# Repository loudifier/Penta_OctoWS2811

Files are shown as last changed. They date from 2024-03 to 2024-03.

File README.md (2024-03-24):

# Penta_OctoWS2811
Adapter board for driving 40 channels of WS2811-style addressable LED strips with a Teensy 4.1 microcontroller

This is a work in progress. A prototype board has been assembled, but I am waiting on parts to test Ethernet, and I am working on a sketch for testing that works better than the teensyduino examples for thousands of LEDs. Committing what I have so far.

[photo of board and LEDs]

The **Penta**_OctoWS2811 is effectively five of the [PJRC OctoWS2811 adapter](https://www.pjrc.com/store/octo28_adaptor.html) squished into a single board for an easy way to take full advantage of the Teensy 4.1's ability to use any set of GPIO pins with the OctoWS2811 library. Penta_OctoWS2811 also adds an Ethernet connector for use with ArtNet or other networked light controller, and a voltage regulator so the board and Teensy can be powered from the LED power supply without USB.

[image of schematic]

## Features

The Penta_OctoWS2811 board has 10 RJ45 ports, for a total of 40 output channels driven from 5V buffers through 100Ω termination resistors. Teensy 4.0 can also be used with this board, supporting up to 24 output channels.

## Usage

The instructions and guidelines on the PJRC website and Teensyduino example scketches for using a Teensy and OctoWS2811 to drive addressible LED strips over CAT6 wires apply equally to the PJRC OctoWS2811 adapter and the Penta_OctoWS2811 board, except for a few key features noted below.

### Output Pins

Teensy 4.1 digital output pins are connected to the following RJ45 ports:  
 Port - GPIO pins  
  J2 - 1, 2, 3, 4  
  J3 - 5, 6, 7, 8  
  J4 - 25, 26, 27, 28  
  J5 - 29, 30, 31, 32  
  J6 - 23, 22, 21, 20  
  J7 - 17, 16, 15, 14  
  J8 - 40, 39, 38, 37  
  J9 - 36, 35, 34, 33  
  J10 - 13, 18, 19, 9  
  J11 - 11, 12, 41, 24

Teensy 4.0 is compatible with the board, and will be connected to J2, J3, J6, J7, J10, and J11. In order to get a full 24 channels of output with Teensy 4.0, GPIO 0 can be used instead of GPIO 41 and GPIO 12 can be used instead of GPIO 24 by shorting jumper pads on the bottom of the board.

A frame sync output is provided, if you somehow need even more output channels and need to maintain accurate timing between multiple boards. The connector can also be useful for connecting to a single 3.3V-compatible LED strip. If you need to use GPIO 12 for SPI communication, you can cut and jump the appropriate pads on the bottom of the board to use GPIO 0 instead.

### Power

Just like the PJRC OctoWS2811 adapter, the Penta_OctoWS2811 board can be powered from your LED power supply. The Penta_OctoWS2811 board adds a voltage regulator for compatibility with newer 12V LED strips. If you are using 5V LEDs, the voltage regulator should be bypassed using the jumper pads on top of the board.

**The Teensy VUSB jumper must be cut if you plan to power the board from the LED power supply.** If you cut the VUSB jumper you can add a single header pin connection fom the Teensy VUSB pad to a corresponding pad on the board, which will allow the Teensy and board to be powered from the LED power supply or USB via a diode.

### Ethernet

## Board Design, Pre-assembled Boards

## Testing

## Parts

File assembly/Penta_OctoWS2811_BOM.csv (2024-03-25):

Designator | Qty | Description | Manufacturer Part Number | Manufacturer | Supplier | DNP
C1,C2,C5,C6,C7,C9 | 6 | CAP 0.1uF 0603 50V X7R 10% | CC0603KRX7R9BB104 | Yageo | LCSC
C3,C4,C8 | 3 | CAP 10uF 0603 25V X5R 20% | CL10A106MA8NRNC | Samsung | LCSC
D1 | 1 | BAT54C dual Schottky barrier diode, common cathode | BAT54C,215 | Nexperia | LCSC
J1 | 1 | 3 pin screw terminal block, 5.08mm pitch | DB127V-5.08-3P-GN-S | Dorabo | LCSC
J2,J3,J4,J5,J6,J7,J8,J9,J10,J11 | 10 | RJ45 jack, 8P8C, unshielded | HC-RJ45-5622-1-6 | HCTL | LCSC
J12 | 1 | RJ45 magjack | J1B1211CCD | WIZnet | LCSC
J13 | 1 | 2x3 2mm header receptacle | ZX-PM2.0-2-3PY | Megastar | LCSC
J14,J15 | 2 | 1x24 2.54mm header receptacle | X6511FV-24-C85D32 | Megastar
J16 | 1 | Single pin 2.54mm header receptacle (use single segment from breakaway strip)
R1,R2,R3,R4,R5,R6,R7,R8,R9,R10,R11,R12,R13,R14,R15,R16,R17,R18,R19,R20,R21,R22,R23,R24,R25,R26,R27,R28,R29,R30,R31,R32,R33,R34,R35,R36,R37,R38,R39,R40,R41 | 41 | RES 100R 0603 1/16W 1% | 0603WAF1000T5E | Uniroyal | LCSC
U1,U2,U5,U6,U7 | 5 | 74HCT245 Octal BUS Transceiver, 3-State outputs, TTL input | 74HCT245D,653 | Nexperia | LCSC
U3 | 1 | NCP1117 1A Low drop-out regulator, Fixed 5.0V, SOT-223 | NCP1117LPST50T3G | onsemi | LCSC

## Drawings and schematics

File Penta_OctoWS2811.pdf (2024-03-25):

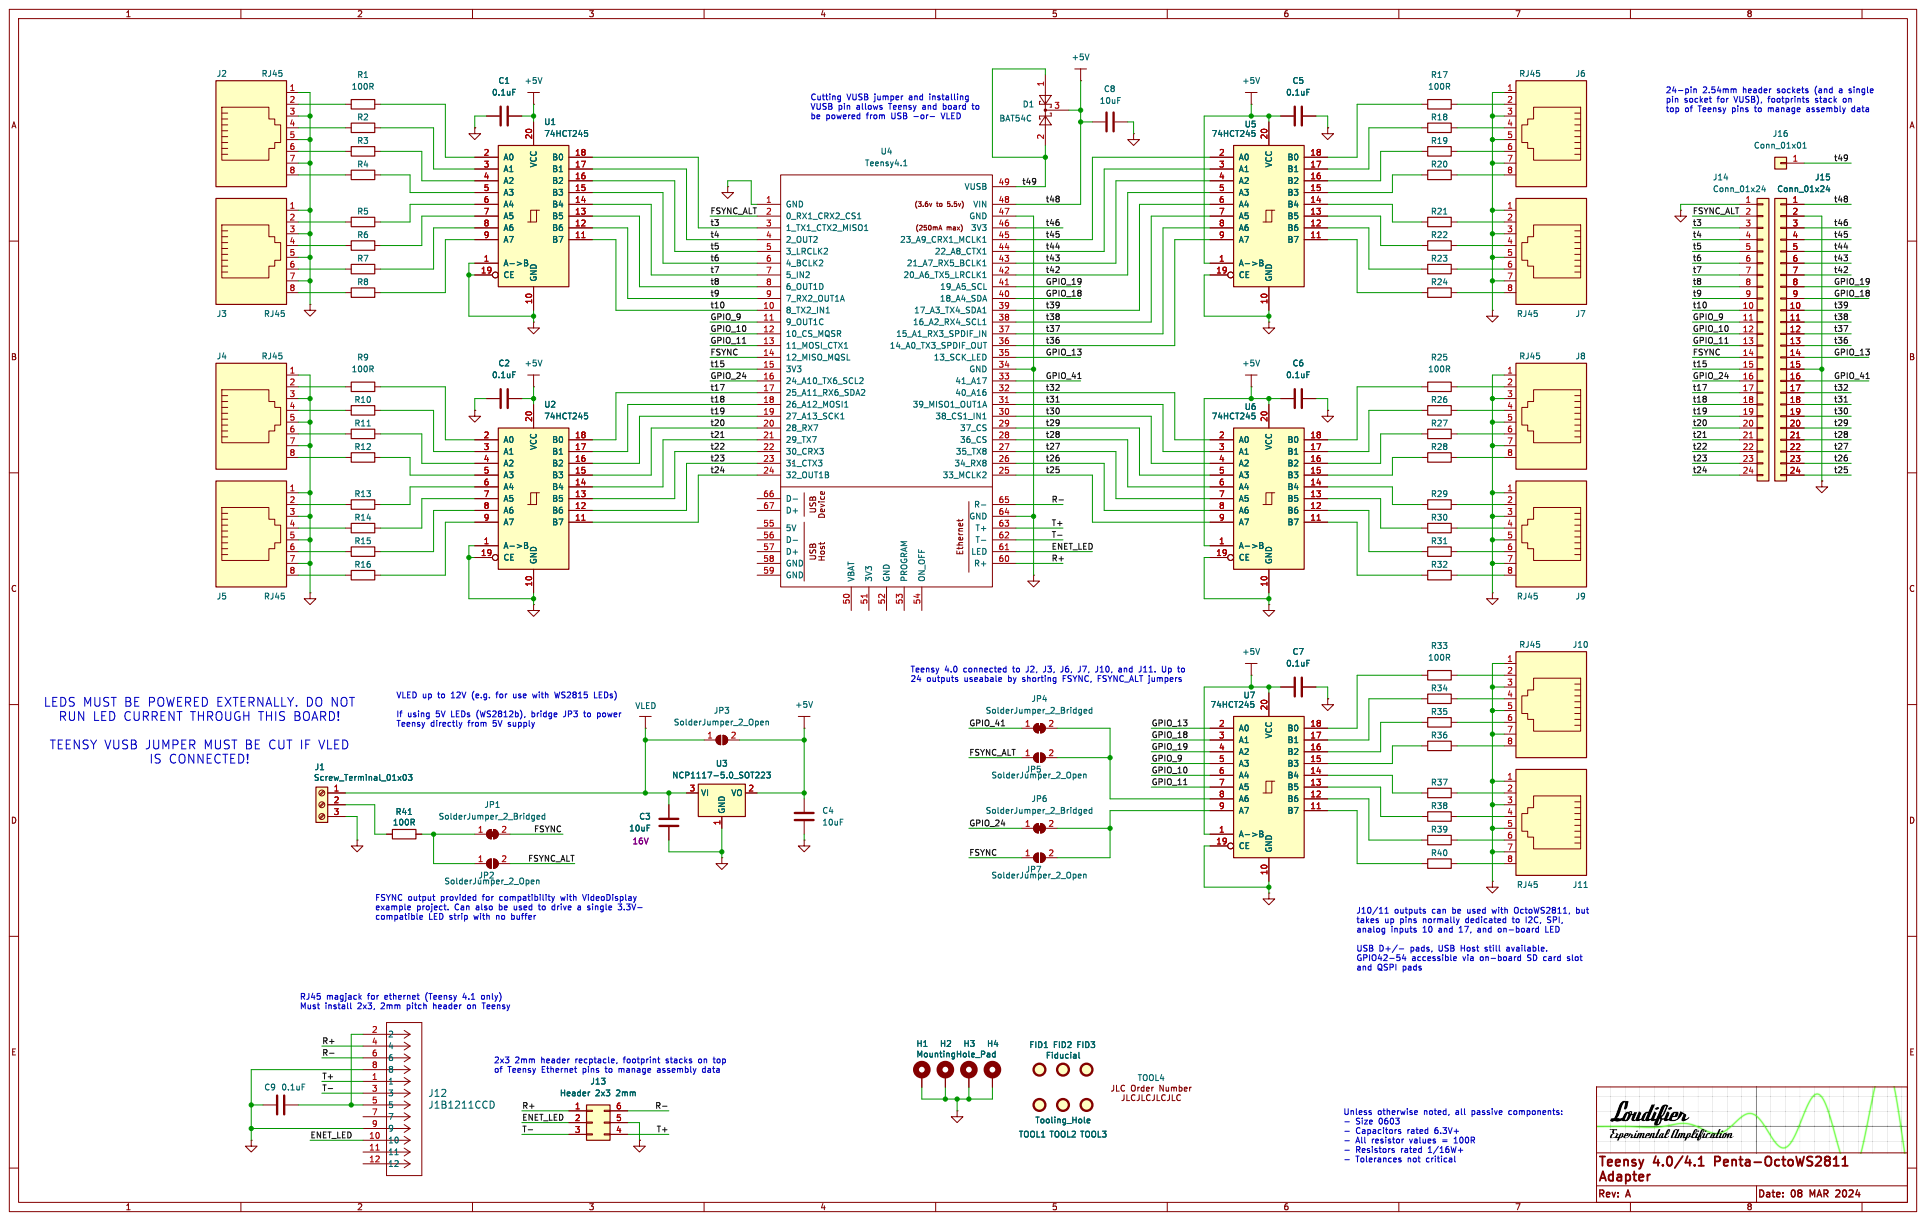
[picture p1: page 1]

top of Teensy pins to manage assembly data

Cutting VUSB jumper and installing VUSB pin allows Teensy and board to

RUN LED CURRENT THROUGH THIS BOARD!

VLED up to 12V (e.g. for use with WS2815 LEDs)

TEENSY VUSB JUMPER MUST BE CUT IF VLED

of Teensy Ethernet pins to manage assembly data

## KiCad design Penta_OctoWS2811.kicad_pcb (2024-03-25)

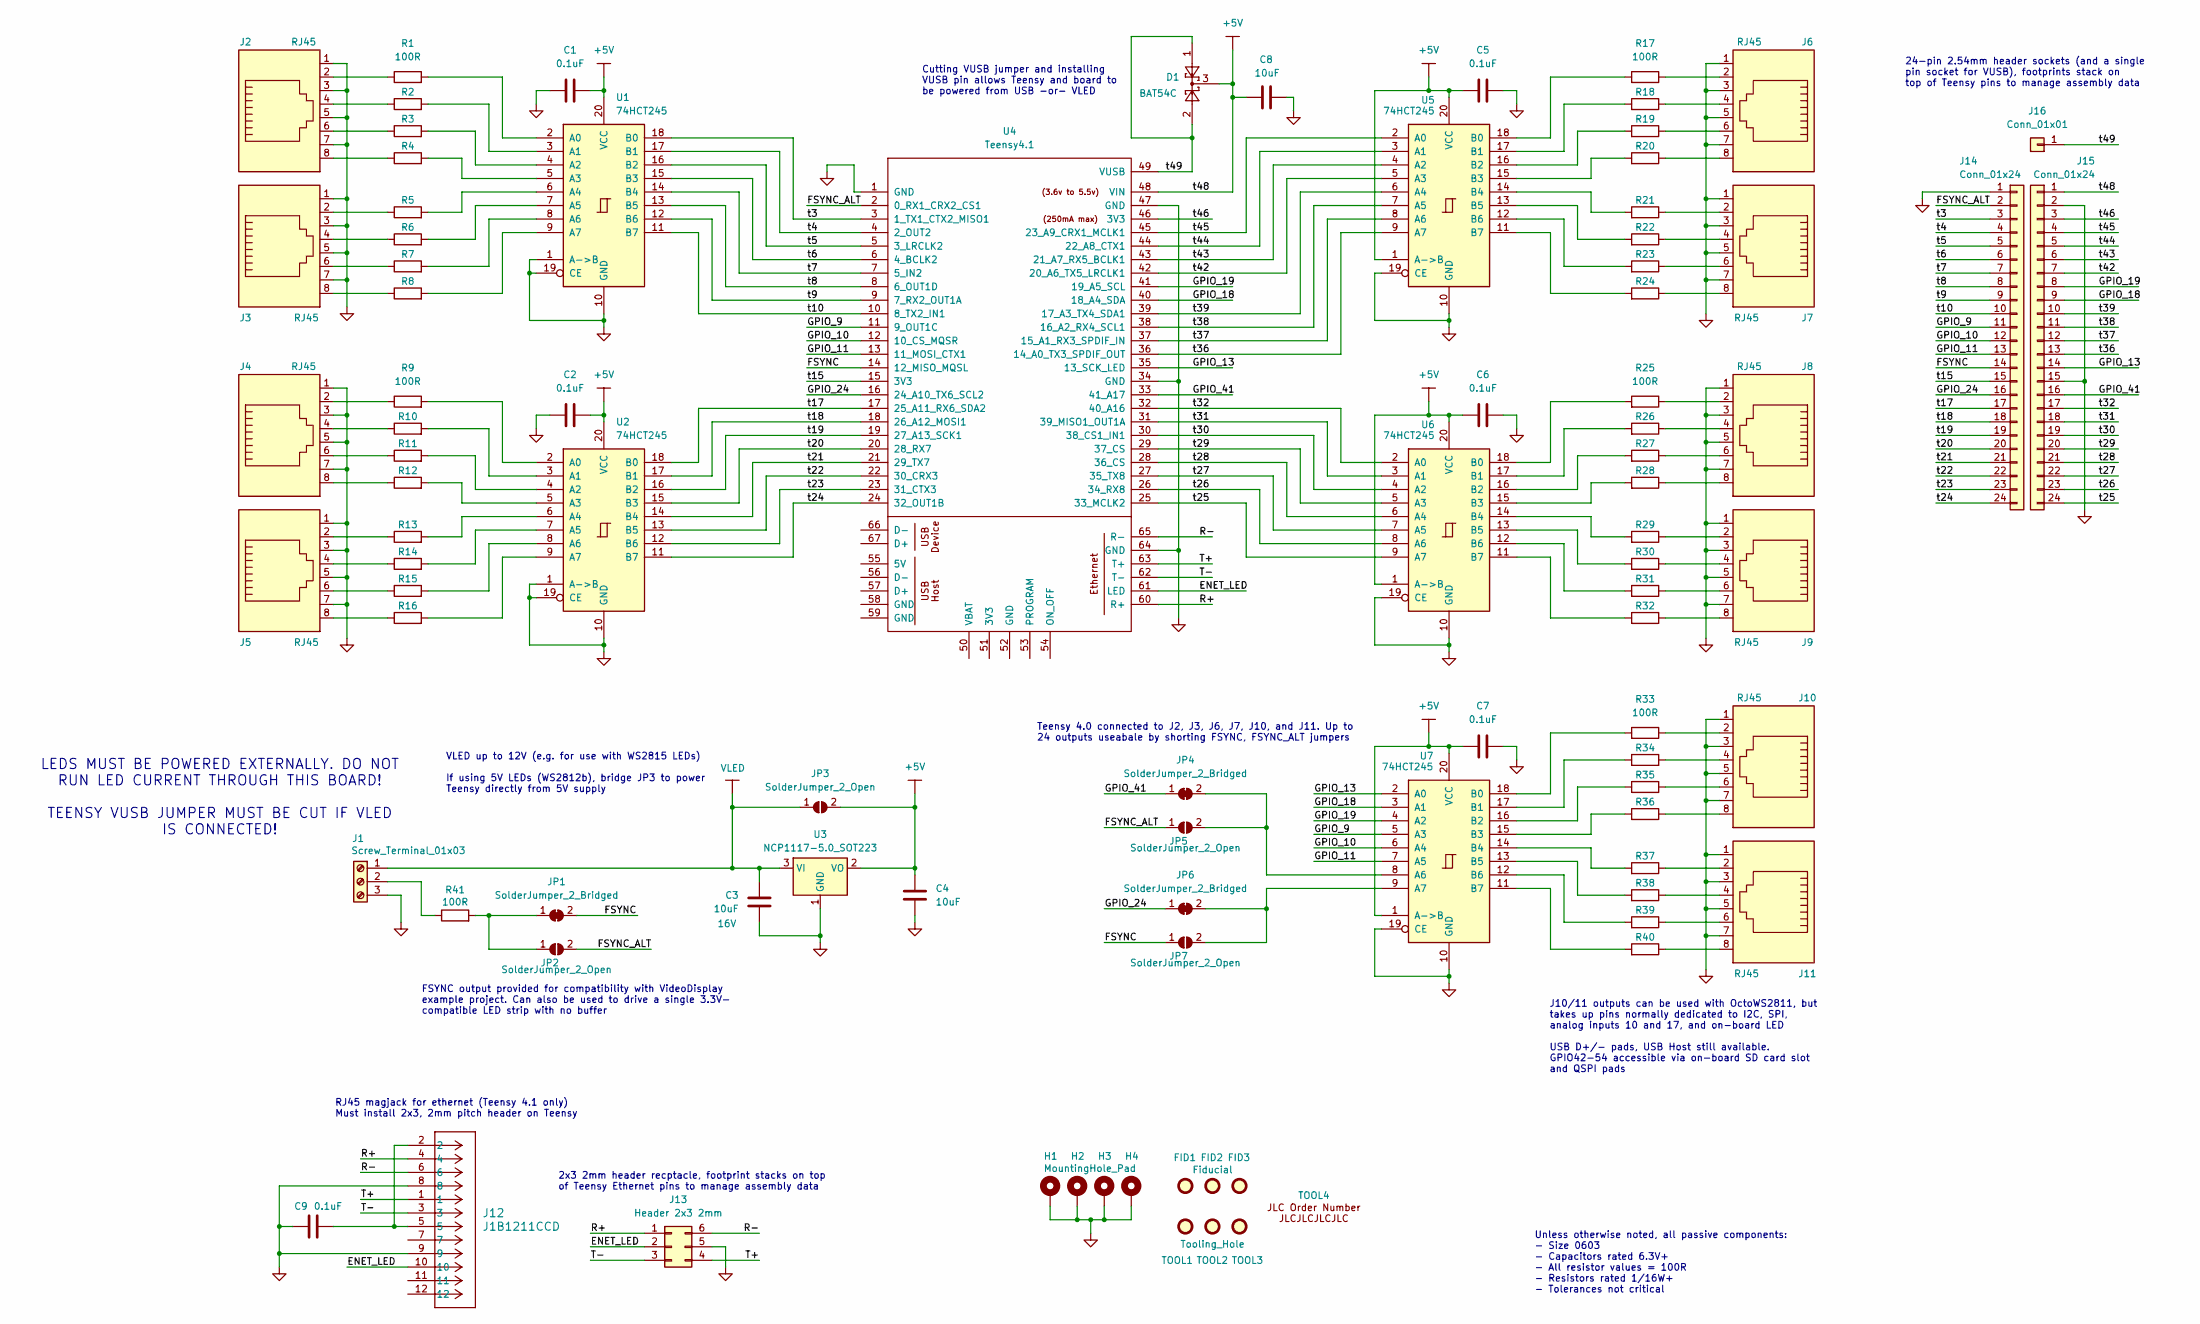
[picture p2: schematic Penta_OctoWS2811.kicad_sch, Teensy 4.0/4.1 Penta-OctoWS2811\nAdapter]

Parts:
C1, C2, C5, C6, C7, C9: 0.1uF; C_0603_1608Metric_Pad1.08x0.95mm_HandSolder; Manufacturer Part Number CC0603KRX7R9BB104
C3: 10uF; C_0603_1608Metric_Pad1.08x0.95mm_HandSolder; Voltage 16V; Manufacturer Part Number CL10A106MA8NRNC
C4, C8: 10uF; C_0603_1608Metric_Pad1.08x0.95mm_HandSolder; Manufacturer Part Number CL10A106MA8NRNC
D1: BAT54C; SOT-23; Manufacturer Part Number BAT54C,215
FID1, FID2, FID3: Fiducial; Fiducial_0.5mm_Mask1mm
H1, H2, H3, H4: MountingHole_Pad; MountingHole_5.3mm_M5_Pad
J1: Screw_Terminal_01x03; TerminalBlock_bornier-3_P5.08mm; Manufacturer Part Number DB127V-5.08-3P-GN-S
J2, J3, J4, J5, J6, J7, J8, J9, J10, J11: RJ45; HCTL HC-RJ45-5622-1-6; Manufacturer Part Number HC-RJ45-5622-1-6
J12: J1B1211CCD; CONN12_J1B1211CCD_WIZ; Manufacturer Part Number J1B1211CCD
J13: Header 2x3 2mm; PinSocket_2x03_P2.00mm_Vertical; Manufacturer Part Number ZX-PM2.0-2-3PY
J14, J15: Conn_01x24; PinSocket_1x24_P2.54mm_Vertical; Manufacturer Part Number X6511FV-24-C85D32
J16: Conn_01x01; PinSocket_1x01_P2.54mm_Vertical
JP1, JP4, JP6: SolderJumper_2_Bridged; SolderJumper-2_P1.3mm_Bridged_RoundedPad1.0x1.5mm
JP2, JP3, JP5, JP7: SolderJumper_2_Open; SolderJumper-2_P1.3mm_Open_RoundedPad1.0x1.5mm
R1, R2, R3, R4, R5, R6, R7, R8, R9, R10, R11, R12, R13, R14, R15, R16, R17, R18, R19, R20, R21, R22, R23, R24, R25, R26, R27, R28, R29, R30, R31, R32, R33, R34, R35, R36, R37, R38, R39, R40, R41: 100R; R_0603_1608Metric_Pad0.98x0.95mm_HandSolder; Manufacturer Part Number 0603WAF1000T5E
TOOL1, TOOL2, TOOL3: Tooling_Hole; Tooling Hole
TOOL4: Order Number
U1, U2, U5, U6, U7: 74HCT245; SOIC-20W_7.5x12.8mm_P1.27mm; Manufacturer Part Number 74HCT245D,653
U3: NCP1117-5.0_SOT223; SOT-223-3_TabPin2; Manufacturer Part Number NCP1117LPST50T3G
U4: Teensy4.1; Teensy41

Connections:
+5V: C1.2, C2.2, C4.2, C5.2, C6.2, C7.2, C8.2, D1.3, J15.1, JP3.2 (B), U1.20 (VCC), U2.20 (VCC), U3.2 (VO), U4.48 (VIN), U5.1 (A->B), U5.20 (VCC), U6.1 (A->B), U6.20 (VCC), U7.1 (A->B), U7.20 (VCC)
/ENET_LED: J12.10, J13.2, U4.61 (LED)
/FSYNC: J14.14, JP1.2 (B), JP7.1 (A), U4.14 (12_MISO_MQSL)
/FSYNC_ALT: J14.2, JP2.2 (B), JP5.1 (A), U4.2 (0_RX1_CRX2_CS1)
/GPIO_9: J14.11, U4.11 (9_OUT1C), U7.5 (A3)
/GPIO_10: J14.12, U4.12 (10_CS_MQSR), U7.6 (A4)
/GPIO_11: J14.13, U4.13 (11_MOSI_CTX1), U7.7 (A5)
/GPIO_13: J15.14, U4.35 (13_SCK_LED), U7.2 (A0)
/GPIO_18: J15.9, U4.40 (18_A4_SDA), U7.3 (A1)
/GPIO_19: J15.8, U4.41 (19_A5_SCL), U7.4 (A2)
/GPIO_24: J14.16, JP6.1 (A), U4.16 (24_A10_TX6_SCL2)
/GPIO_41: J15.16, JP4.1 (A), U4.33 (41_A17)
/R+: J12.4, J13.1, U4.60 (R+)
/R-: J12.6, J13.6, U4.65 (R-)
/T+: J12.1, J13.4, U4.63 (T+)
/T-: J12.3, J13.3, U4.62 (T-)
/t3: J14.3, U1.18 (B0), U4.3 (1_TX1_CTX2_MISO1)
/t4: J14.4, U1.17 (B1), U4.4 (2_OUT2)
/t5: J14.5, U1.16 (B2), U4.5 (3_LRCLK2)
/t6: J14.6, U1.15 (B3), U4.6 (4_BCLK2)
/t7: J14.7, U1.14 (B4), U4.7 (5_IN2)
/t8: J14.8, U1.13 (B5), U4.8 (6_OUT1D)
/t9: J14.9, U1.12 (B6), U4.9 (7_RX2_OUT1A)
/t10: J14.10, U1.11 (B7), U4.10 (8_TX2_IN1)
/t15: J14.15, U4.15 (3V3)
/t17: J14.17, U2.18 (B0), U4.17 (25_A11_RX6_SDA2)
/t18: J14.18, U2.17 (B1), U4.18 (26_A12_MOSI1)
/t19: J14.19, U2.16 (B2), U4.19 (27_A13_SCK1)
/t20: J14.20, U2.15 (B3), U4.20 (28_RX7)
/t21: J14.21, U2.14 (B4), U4.21 (29_TX7)
/t22: J14.22, U2.13 (B5), U4.22 (30_CRX3)
/t23: J14.23, U2.12 (B6), U4.23 (31_CTX3)
/t24: J14.24, U2.11 (B7), U4.24 (32_OUT1B)
/t25: J15.24, U4.25 (33_MCLK2), U6.9 (A7)
/t26: J15.23, U4.26 (34_RX8), U6.8 (A6)
/t27: J15.22, U4.27 (35_TX8), U6.7 (A5)
/t28: J15.21, U4.28 (36_CS), U6.6 (A4)
/t29: J15.20, U4.29 (37_CS), U6.5 (A3)
/t30: J15.19, U4.30 (38_CS1_IN1), U6.4 (A2)
/t31: J15.18, U4.31 (39_MISO1_OUT1A), U6.3 (A1)
/t32: J15.17, U4.32 (40_A16), U6.2 (A0)
/t36: J15.13, U4.36 (14_A0_TX3_SPDIF_OUT), U5.9 (A7)
/t37: J15.12, U4.37 (15_A1_RX3_SPDIF_IN), U5.8 (A6)
/t38: J15.11, U4.38 (16_A2_RX4_SCL1), U5.7 (A5)
/t39: J15.10, U4.39 (17_A3_TX4_SDA1), U5.6 (A4)
/t42: J15.7, U4.42 (20_A6_TX5_LRCLK1), U5.5 (A3)
/t43: J15.6, U4.43 (21_A7_RX5_BCLK1), U5.4 (A2)
/t44: J15.5, U4.44 (22_A8_CTX1), U5.3 (A1)
/t45: J15.4, U4.45 (23_A9_CRX1_MCLK1), U5.2 (A0)
/t46: J15.3, U4.46 (3V3)
/t49: D1.1, D1.2, J16.1, U4.49 (VUSB)
GND: C1.1, C2.1, C3.1, C4.1, C5.1, C6.1, C7.1, C8.1, C9.1, H1.1, H2.1, H3.1, H4.1, J1.3, J2.1, J2.3, J2.5, J2.7, J3.1, J3.3, J3.5, J3.7, J4.1, J4.3, J4.5, J4.7, J5.1, J5.3, J5.5, J5.7, J6.1, J6.3, J6.5, J6.7, J7.1, J7.3, J7.5, J7.7, J8.1, J8.3, J8.5, J8.7, J9.1, J9.3, J9.5, J9.7, J10.1, J10.3, J10.5, J10.7, J11.1, J11.3, J11.5, J11.7, J12.8, J12.9, J13.5, J14.1, J15.2, J15.15, U1.1 (A->B), U1.10 (GND), U1.19 (CE), U2.1 (A->B), U2.10 (GND), U2.19 (CE), U3.1 (GND), U4.1 (GND), U4.34 (GND), U4.47 (GND), U4.64 (GND), U5.10 (GND), U5.19 (CE), U6.10 (GND), U6.19 (CE), U7.10 (GND), U7.19 (CE)
unnamed: C9.2, J12.2, J12.5
unnamed: J1.2, R41.1
unnamed: J2.2, R1.1
unnamed: J2.4, R2.1
unnamed: J2.6, R3.1
unnamed: J2.8, R4.1
unnamed: J3.2, R5.1
unnamed: J3.4, R6.1
unnamed: J3.6, R7.1
unnamed: J3.8, R8.1
unnamed: J4.2, R9.1
unnamed: J4.4, R10.1
unnamed: J4.6, R11.1
unnamed: J4.8, R12.1
unnamed: J5.2, R13.1
unnamed: J5.4, R14.1
unnamed: J5.6, R15.1
unnamed: J5.8, R16.1
unnamed: J6.2, R17.1
unnamed: J6.4, R18.1
unnamed: J6.6, R19.1
unnamed: J6.8, R20.1
unnamed: J7.2, R21.1
unnamed: J7.4, R22.1
unnamed: J7.6, R23.1
unnamed: J7.8, R24.1
unnamed: J8.2, R25.1
unnamed: J8.4, R26.1
unnamed: J8.6, R27.1
unnamed: J8.8, R28.1
unnamed: J9.2, R29.1
unnamed: J9.4, R30.1
unnamed: J9.6, R31.1
unnamed: J9.8, R32.1
unnamed: J10.2, R33.1
unnamed: J10.4, R34.1
unnamed: J10.6, R35.1
unnamed: J10.8, R36.1
unnamed: J11.2, R37.1
unnamed: J11.4, R38.1
unnamed: J11.6, R39.1
unnamed: J11.8, R40.1
unnamed: JP1.1 (A), JP2.1 (A), R41.2
unnamed: JP4.2 (B), JP5.2 (B), U7.8 (A6)
unnamed: JP6.2 (B), JP7.2 (B), U7.9 (A7)
unnamed: R1.2, U1.2 (A0)
unnamed: R2.2, U1.3 (A1)
unnamed: R3.2, U1.4 (A2)
unnamed: R4.2, U1.5 (A3)
unnamed: R5.2, U1.6 (A4)
unnamed: R6.2, U1.7 (A5)
unnamed: R7.2, U1.8 (A6)
unnamed: R8.2, U1.9 (A7)
unnamed: R9.2, U2.2 (A0)
unnamed: R10.2, U2.3 (A1)
unnamed: R11.2, U2.4 (A2)
unnamed: R12.2, U2.5 (A3)
unnamed: R13.2, U2.6 (A4)
unnamed: R14.2, U2.7 (A5)
unnamed: R15.2, U2.8 (A6)
unnamed: R16.2, U2.9 (A7)
unnamed: R17.2, U5.18 (B0)
unnamed: R18.2, U5.17 (B1)
unnamed: R19.2, U5.16 (B2)
unnamed: R20.2, U5.15 (B3)
unnamed: R21.2, U5.14 (B4)
unnamed: R22.2, U5.13 (B5)
unnamed: R23.2, U5.12 (B6)
unnamed: R24.2, U5.11 (B7)
unnamed: R25.2, U6.18 (B0)
unnamed: R26.2, U6.17 (B1)
unnamed: R27.2, U6.16 (B2)
unnamed: R28.2, U6.15 (B3)
unnamed: R29.2, U6.14 (B4)
unnamed: R30.2, U6.13 (B5)
unnamed: R31.2, U6.12 (B6)
unnamed: R32.2, U6.11 (B7)
unnamed: R33.2, U7.18 (B0)
unnamed: R34.2, U7.17 (B1)
unnamed: R35.2, U7.16 (B2)
unnamed: R36.2, U7.15 (B3)
unnamed: R37.2, U7.14 (B4)
unnamed: R38.2, U7.13 (B5)
unnamed: R39.2, U7.12 (B6)
unnamed: R40.2, U7.11 (B7)
VLED: C3.2, J1.1, JP3.1 (A), U3.3 (VI)

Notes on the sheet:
Cutting VUSB jumper and installing VUSB pin allows Teensy and board to be powered from USB -or- VLED
2x3 2mm header recptacle, footprint stacks on top of Teensy Ethernet pins to manage assembly data
LEDS MUST BE POWERED EXTERNALLY. DO NOT RUN LED CURRENT THROUGH THIS BOARD! TEENSY VUSB JUMPER MUST BE CUT IF VLED IS CONNECTED!
24-pin 2.54mm header sockets (and a single pin socket for VUSB), footprints stack on top of Teensy pins to manage assembly data
Unless otherwise noted, all passive components: - Size 0603 - Capacitors rated 6.3V+ - All resistor values = 100R - Resistors rated 1/16W+ - Tolerances not critical
FSYNC output provided for compatibility with VideoDisplay example project. Can also be used to drive a single 3.3V- compatible LED strip with no buffer
J10/11 outputs can be used with OctoWS2811, but takes up pins normally dedicated to I2C, SPI, analog inputs 10 and 17, and on-board LED USB D+/- pads, USB Host still available. GPIO42-54 accessible via on-board SD card slot and QSPI pads
RJ45 magjack for ethernet (Teensy 4.1 only) Must install 2x3, 2mm pitch header on Teensy
Teensy 4.0 connected to J2, J3, J6, J7, J10, and J11. Up to 24 outputs useabale by shorting FSYNC, FSYNC_ALT jumpers
VLED up to 12V (e.g. for use with WS2815 LEDs) If using 5V LEDs (WS2812b), bridge JP3 to power Teensy directly from 5V supply

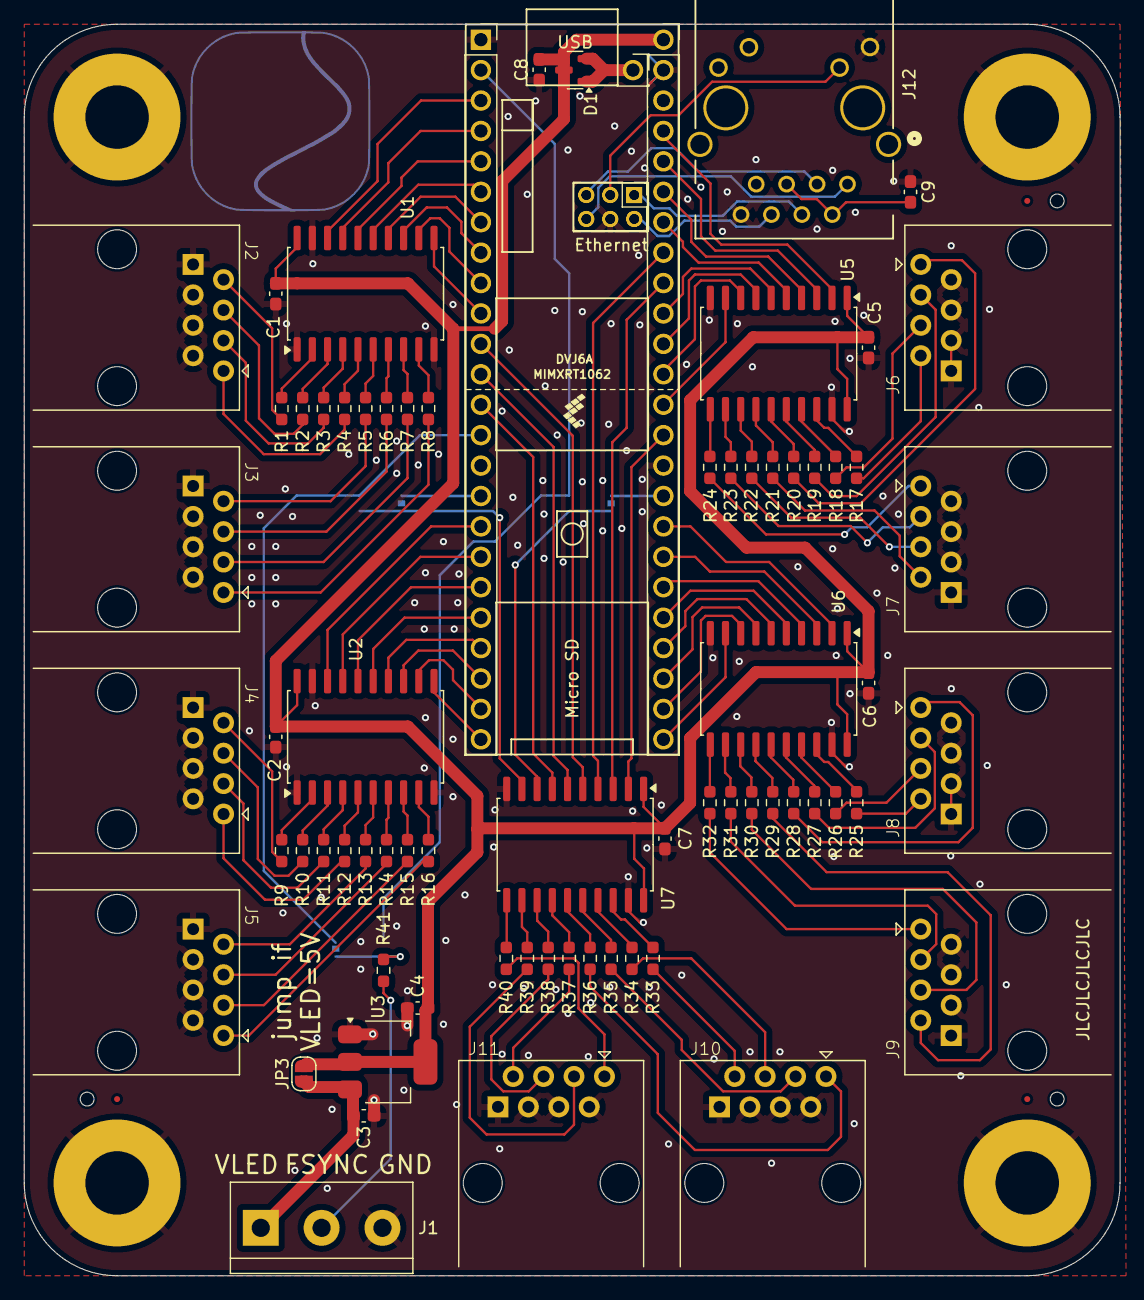
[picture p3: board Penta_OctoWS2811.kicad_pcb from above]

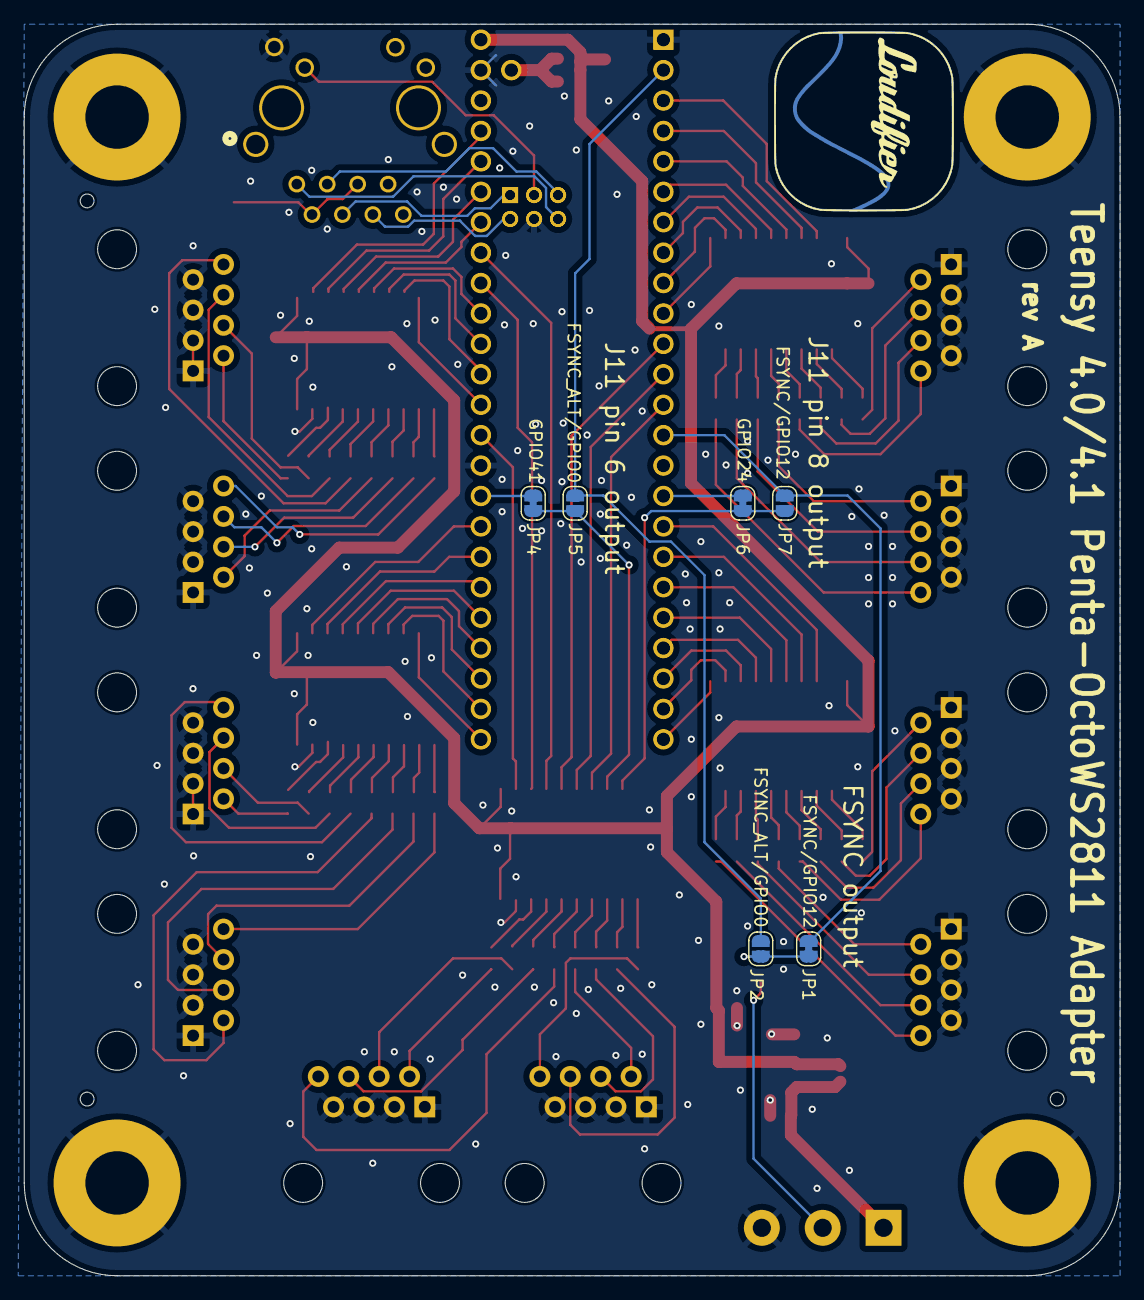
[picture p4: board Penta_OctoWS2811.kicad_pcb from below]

Board: 2 copper layers, 91.5 x 104.5 mm, 92 parts (6 on the bottom side), 138 nets.

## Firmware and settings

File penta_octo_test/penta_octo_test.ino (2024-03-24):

/*  OctoWS2811 Teensy4_PinList.ino - Demonstrate use of any pins
    http://www.pjrc.com/teensy/td_libs_OctoWS2811.html

  With Teensy 4.x, you can use any group of pins.  You are not limited
  to only 8 fixed pins as with Teensy 3.x.  This example shows how to
  use only 4 pins, which are the 4 pins of the Octo28 shield which do
  not conflict with the Audio shield.

  Required Connections
  --------------------
    pin 2:  LED Strip #1
    pin 14: LED strip #2
    pin 6:  LED strip #5
    pin 5:  LED strip #8
*/

#include <OctoWS2811.h>

/* Any group of digital pins may be used
Pinouts of the Penta_OctoWS2811 board (Teensy 4.0 not connected to J4, J5, J8, or J9)
  J2 - 1, 2, 3, 4
  J3 - 5, 6, 7, 8
  J4 - 25, 26, 27, 28
  J5 - 29, 30, 31, 32
  J6 - 23, 22, 21, 20
  J7 - 17, 16, 15, 14
  J8 - 40, 39, 38, 37
  J9 - 36, 35, 34, 33
  J10 - 13, 18, 19, 9
  J11 - 11, 12, 41, 24 (0 can be used instead of 41 and 12 can be used instead of 24 by changing jumper pads on bottom of board)

*/
const int numPins = 40;
byte pinList[numPins] = {1, 2, 3, 4, 5, 6, 7, 8, 25, 26, 27, 28, 29, 30, 31, 32, 23, 22, 21, 20, 17, 16, 15, 14, 40, 39, 38, 37, 36, 35, 34, 33, 13, 18, 19, 9, 11, 12, 41, 24};

const int ledsPerStrip = 1365;


// These buffers need to be large enough for all the pixels.
// The total number of pixels is "ledsPerStrip * numPins".
// Each pixel needs 3 bytes, so multiply by 3.  An "int" is
// 4 bytes, so divide by 4.  The array is created using "int"
// so the compiler will align it to 32 bit memory.
const int bytesPerLED = 3;  // change to 4 if using RGBW
DMAMEM int displayMemory[ledsPerStrip * numPins * bytesPerLED / 4];
int drawingMemory[ledsPerStrip * numPins * bytesPerLED / 4];

const int config = WS2811_GRB | WS2811_800kHz;

OctoWS2811 leds(ledsPerStrip, displayMemory, drawingMemory, config, numPins, pinList);

void setup() {
  leds.begin();
  leds.show();
}

/*
#define RED    0xFF0000
#define GREEN  0x00FF00
#define BLUE   0x0000FF
#define YELLOW 0xFFFF00
#define PINK   0xFF1088
#define ORANGE 0xE05800
#define WHITE  0xFFFFFF
*/
// Less intense...

#define RED    0x160000
#define GREEN  0x001600
#define BLUE   0x000016
#define YELLOW 0x101400
#define PINK   0x120009
#define ORANGE 0x100400
#define WHITE  0x101010


void loop() {
  //int microsec = 2000000 / ledsPerStrip;  // change them all in 2 seconds
  int microsec = -30; // when microsec is set to a negative value, skip that number of frames

  // uncomment for voltage controlled speed
  // millisec = analogRead(A9) / 40;

  colorWipe(RED, microsec);
  colorWipe(GREEN, microsec);
  colorWipe(BLUE, microsec);
  colorWipe(YELLOW, microsec);
  colorWipe(PINK, microsec);
  colorWipe(ORANGE, microsec);
  colorWipe(WHITE, microsec);
}

void colorWipe(int color, int wait)
{
  for (int i=0; i < ledsPerStrip; i++) {
      for (int j=0; j< numPins; j++){
        if (i<j){
          leds.setPixel(j*ledsPerStrip + i, color ^ WHITE);
        } else {
          leds.setPixel(j*ledsPerStrip + i, color);
        }
      }
    if (wait<0){
      if ((i%int(-wait+0.5) == 0)){
        leds.show();
      }
    } else {
      leds.show();
      delayMicroseconds(wait);
    }
  }
}
